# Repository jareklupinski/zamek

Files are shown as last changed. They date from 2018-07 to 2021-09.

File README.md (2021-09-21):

# Zamek
Your Digital Keychain.

I want to design the digital equivalent to the analog keychain. It keeps your passwords for you in an easy-to-use and portable, reliable design. It can be used completely standalone, but also with a Desktop App for easier data input.

Prototypes:

[Youtube Function Demo](https://www.youtube.com/watch?v=8wrW3907pkc)

Zamek Prototype 1

Zamek Prototype 2

Front View:
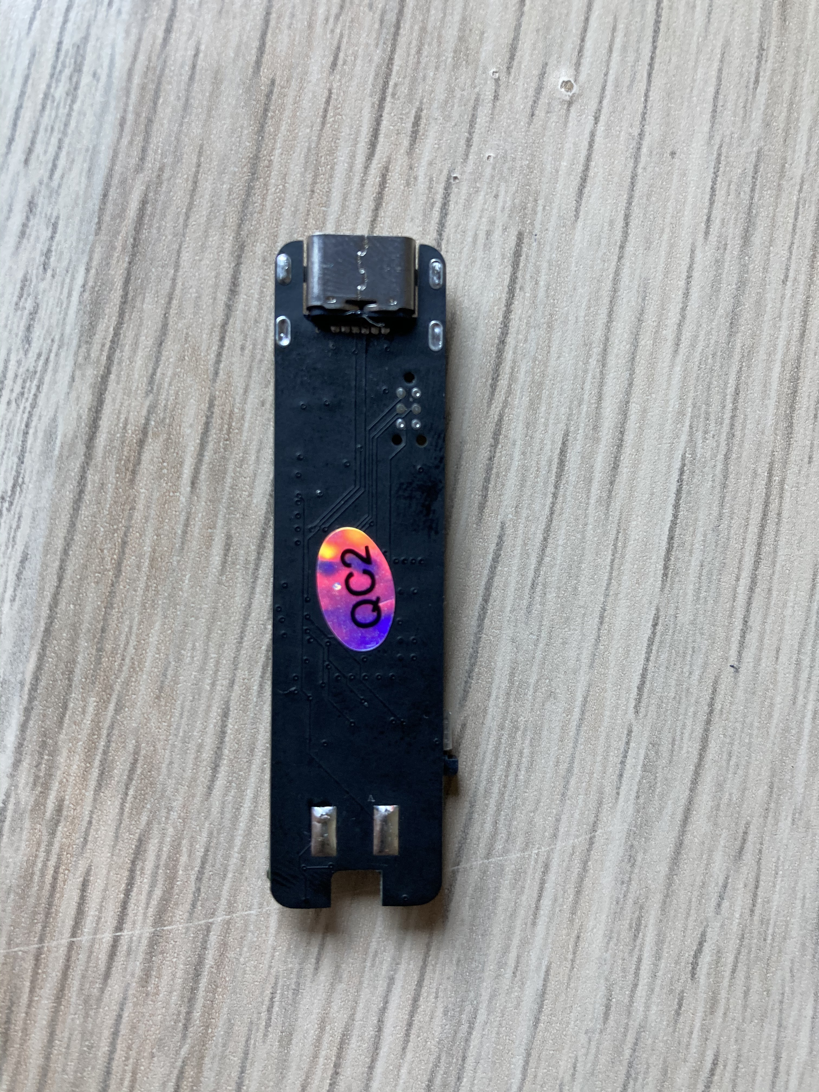
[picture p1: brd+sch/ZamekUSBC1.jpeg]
front-view


Back View:
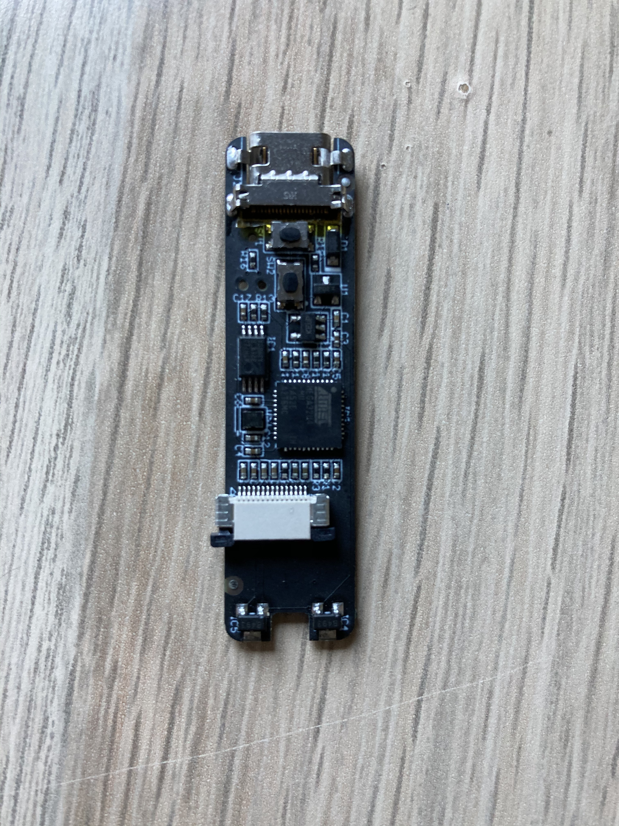
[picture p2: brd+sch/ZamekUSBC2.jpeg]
back-view


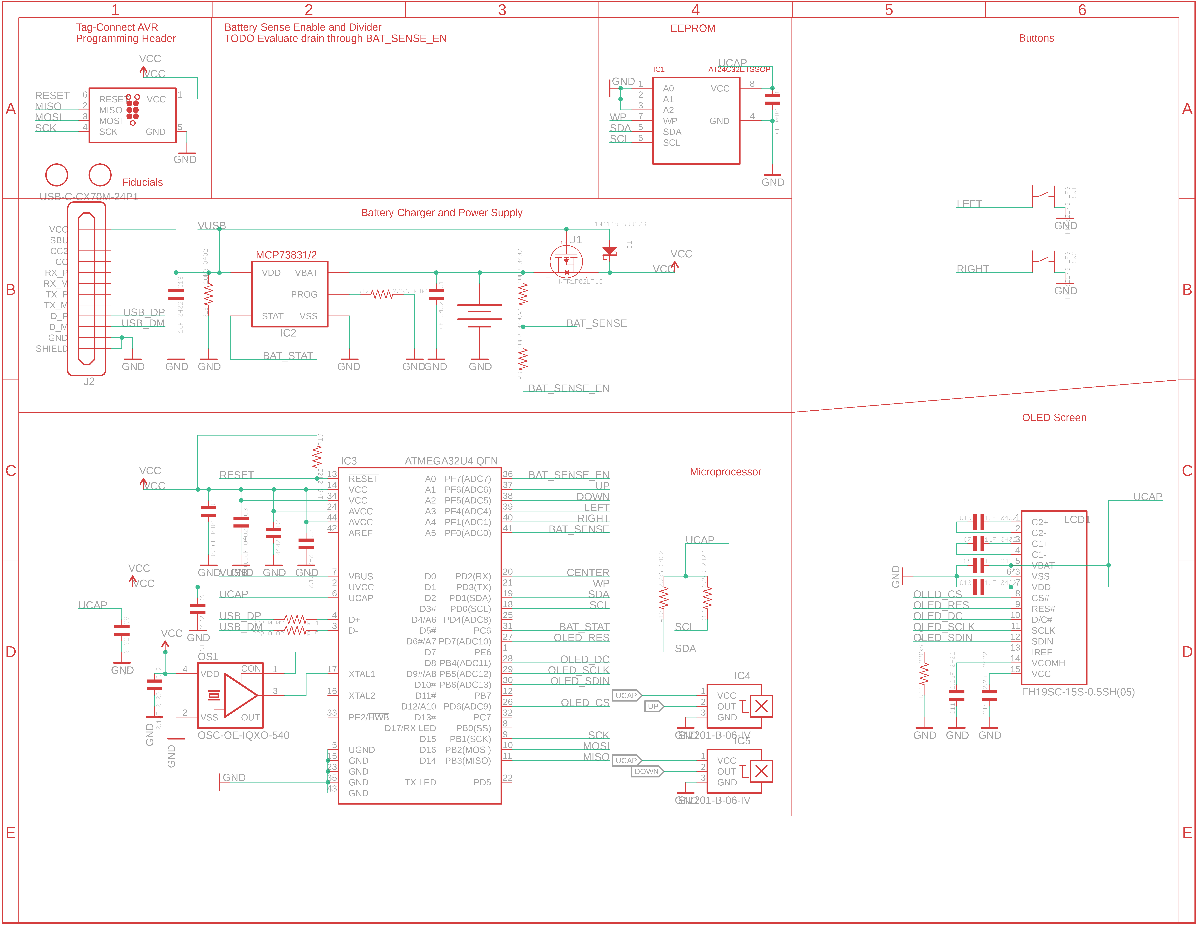
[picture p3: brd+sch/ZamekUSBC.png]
schematic


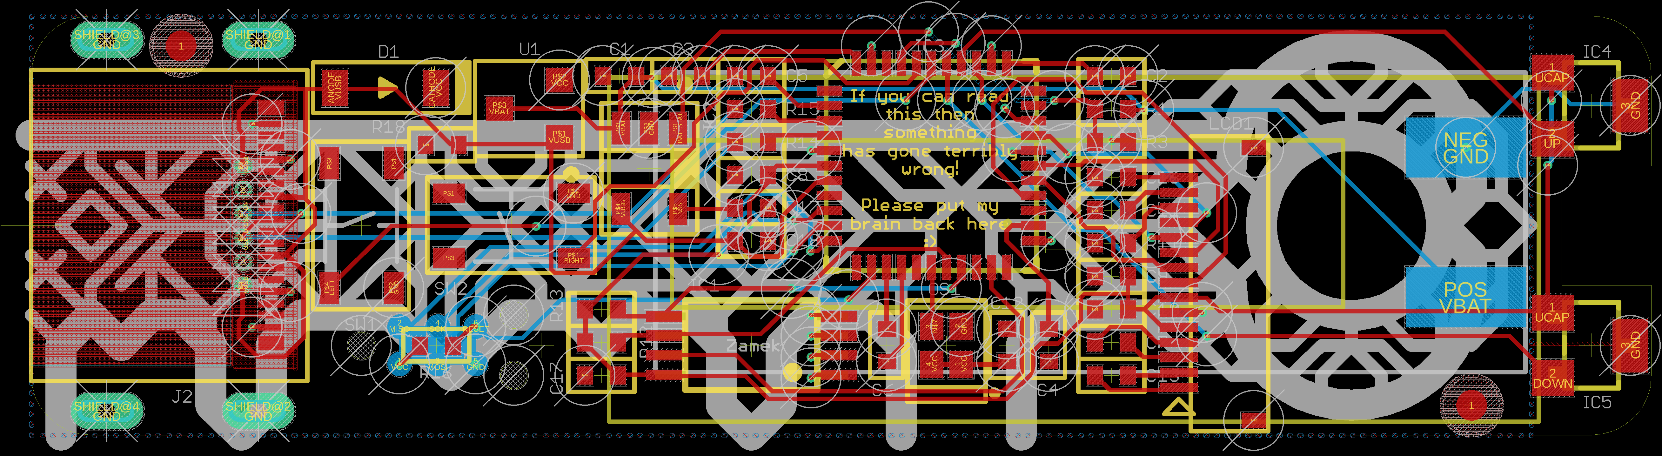
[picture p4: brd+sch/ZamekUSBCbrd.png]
board


This project is a Work-In-Progress; all contributions are welcome!

Project Layout:
* brd+sch contains hardware schematic
* desktop-app contains the desktop app
* zamek-src contains arduino source code

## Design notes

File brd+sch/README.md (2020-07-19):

Actual Schematic:
schematic

Component Layout:
board

Routed, produced, and smoke tested. Some validation with sensors to be done...

Front View:
front-view

Back View:
back-view

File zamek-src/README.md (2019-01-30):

# Arduino Sourcecode for the ATMega32U4

To compile this source code the AESLib is needed [AESLib](https://github.com/DavyLandman/AESLib). Just copy it in your Arduino lib folder.
Also configure Arduino to compile for "Leonardo Compatible" and hit compile. Some warnings are thrown, but the code should run. I've tested the build process on Arduino 1.6.7

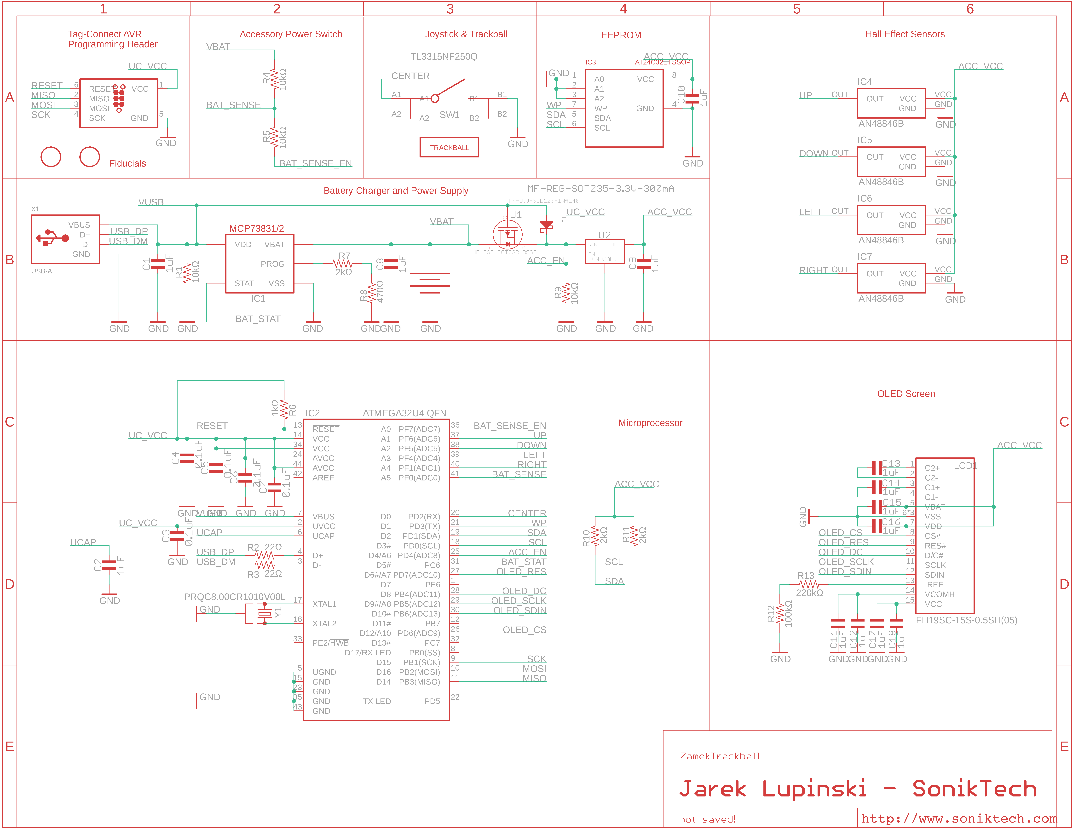
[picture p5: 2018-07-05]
brd+sch/zamek-schematic.png

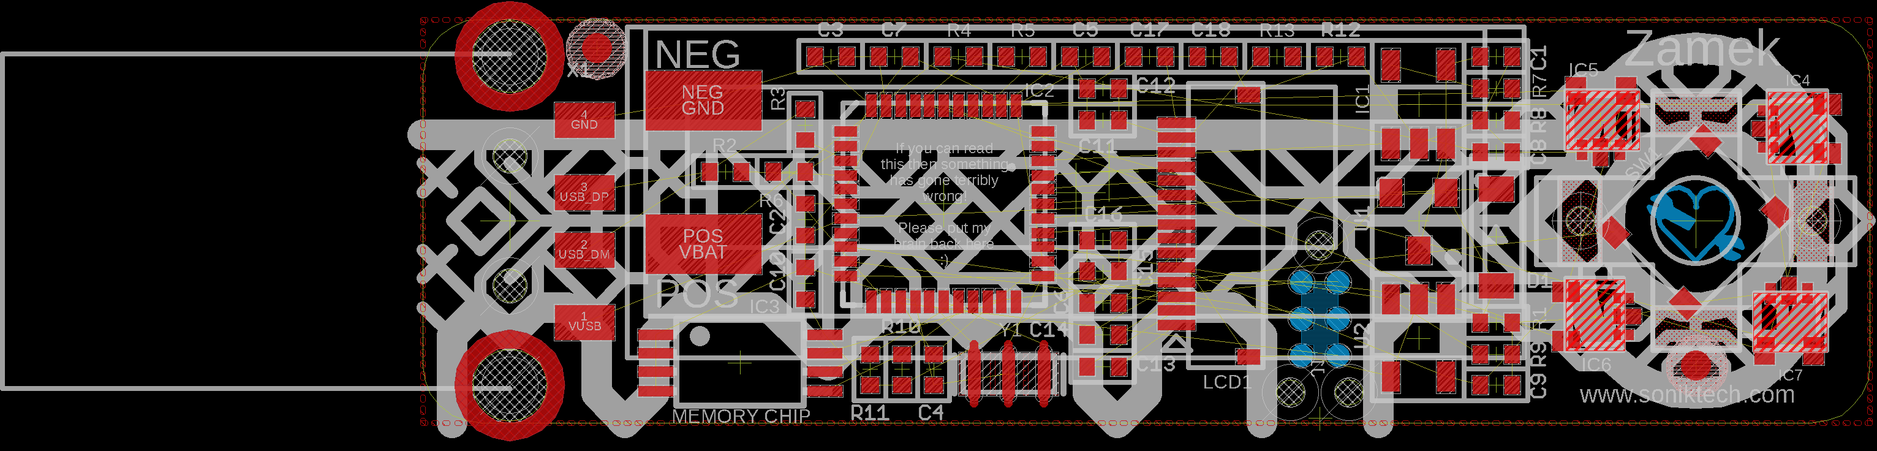
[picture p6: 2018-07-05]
brd+sch/zamek-board.png

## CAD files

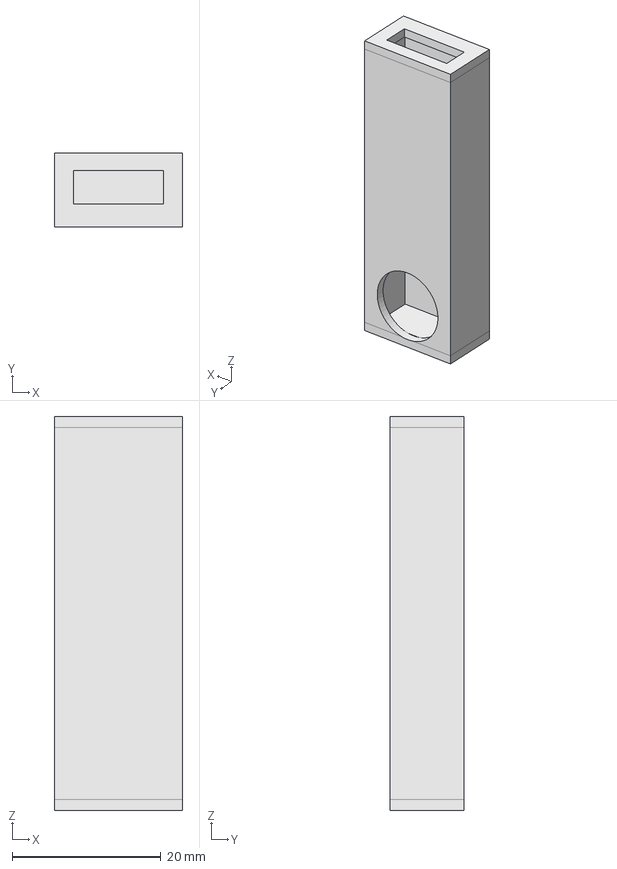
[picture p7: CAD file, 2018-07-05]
brd+sch/zamek.FCStd
17.2 x 10.0 x 53.0 mm

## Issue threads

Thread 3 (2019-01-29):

Serial Protocol undocumented and probably insecure?

vogt31337, 2019-01-29:
Hi,

just browsing through this repo and I like the project so far. But I don't find any docu on the serial protocol used: I just figured out sending a 'd' to the device, will dump the whole eeprom store.
I hope this is just for debugging, and Can be removed...

BR

jareklupinski, 2019-01-30:
Hi vogt, the intention for this is to allow a PC app attached to the Zamek's Serial Port to download the encrypted payload from the device for ease-of-use tasks like credential entry and backups. As only the encrypted blob can be downloaded, the PC still needs whichever key you put into the device to decrypt the contents. This will ( in the future ) be something the user has to toggle, something like a dialog will pop up on the device requesting the user to confirm their blob is about to be dumped before it actually connects and dumps.

-d for dump :)

Closed 2019-01-30.

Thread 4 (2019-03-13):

Security: weak key material used for encrypting passwords

rosly, 2019-03-13:
Hi,

Just by quick search I found this in zamekSecurity.unlock():
23: key[ i ] = pinArray[ i ];
28:   aes128_cbc_enc( key, iv, data, 48 )

Means that all the key entropy came from PIN, which can be from 1 to 16 ASCII digits.
Combining that with user tendency to use short PINs this solution is far from secure.
Obviously, for 4 digit PIN we have 9999 key space.
On my PC CPU only I would be able to crack data secured by this method up to 13 digits PIN just in one day.

Probably most of the people will use PINs far shorter than 13 digits.
That's just if we considering entropy. The key should never be pure ASCII string.
You need to use proper encryption scheme.

jareklupinski, 2019-03-13:
Hi! Thanks for opening this issue; security is one of the aspects of this project I wanted to compartmentalize to easily get and implement feedback.

My intentions for this device is to allow the user to choose their own security level. For example, I choose a 4-digit PIN for my Zamek because I am sure that I would be able to change all of my passwords in less than a day if I lose my device ( using a backup I keep at home ). Other people may choose longer passwords to get extra time.

The balance between convenience and security is tough and I want to leave this issue open for discussion :)

One idea I had was to initialize the password store with a completely random 16-digit number and allow the user to edit certain digits, e.g. your randomly generated seed is 123456789abcdef, and your PIN is 4031, then the seed would be 403156789abcdef. Storing these last few digits somewhere other than a secure store is a weakness, but it needs to be nonvolatile... I assume if someone has hardware access then they can dump your payload and anything else on the device at will, so at most this should give you some extra time to change your passwords if your device gets stolen.... This probably needs input from a security expert.

ventaquil, 2019-03-13:
In my opinion you should use [key derivation function](https://en.wikipedia.org/wiki/Key_derivation_function). This crypto scheme turns input into fixed-size key (for your usage it turns PIN into 128 bits length AES key).

You can use AES-KDF scheme (which is used by KeePass) or [PBKDF2](https://en.wikipedia.org/wiki/PBKDF2) (it is more flexible solution because you can choose pseudorandom function which determines security).

An additional advantage of using KDF is that this solution can stronger resist against offline attacks. You can check it on your own - just create KeePass database and in database's settings set _"1 second delay"_ to calculate how many iterations of KDF should be set to have 1 second computation of one password on your machine.

rosly, 2019-03-13:
Hi,

I know this is a long post but all this explanation is probably needed to clarify some misunderstandings.

Key entropy depends only on how random your key material is.
It didn't mater if you use 16 digits but edit only some of them as the entropy of this solution is exactly the same as if you enter only those random digits. You probably were thinking about hash salt, which is in fact one of the ways to harden the security but in vector of rainbow tables attack. Anyway to use this you need to use hashes for key material which was one elements of "proper encryption scheme".

But lets first clarify why your current PIN need to be long. The entropy of single ASCII digit is log2(10) = 3.322 bits (yes might seems odd that there are fraction of bits).
On the other hand the iCore5 makes 55 millions of AES128 blocks encryption per second.

It means that with 4 ASCII digit key material you have ~13bit entropy for the key, which is 2^14 - 1 = 16384 combinations that can be cracked with speed 55 millions tries per second in ~ 0.2ms
Which means if you lose your device you would need to have 0.2 millisecond reaction time :) (not to much)

Ok, that was a bit of nerd joke from my side ;)
So if we make our scenario more realistic. Lets assume that you will have reaction time of 6 hours (this includes time for spotting that you lost the device, like after returning home and time required to change all the passwords). If we also assume that the attacker would have 10 machines with 12 cores (which is not big number as you can buy 6h of computing time for such cluster under 10$ and as you already noted in your code you only need to decrypt first block of 16 bytes to reject garbage non ASCII output), that's 55M/s * 12 * 10 = 6.6 billions blocks per second. And that's not even close to what some guys have for serious cracking on GPU farms or zombie botnet.

So:
6.6*10^9 * 3600 * 6h = 1.4256*10^14 blocks decrypted during 6h window
log2(1.4256*10^14) = 47 bits entropy scanned during the 6h window
47/3.322 -> ~14 ASCII digit PIN
or 47/5.12 -> ~9 ASCII small letters and digits PIN

As you see those are rather long PINs. This might be problematic with current method of PIN input (or we should rather say password as those attacks are offline attack), as 14 digits is unpractical and 9 letter or digits might take a while to scroll through.

As the solution I propose:
- as I assume the power of HW device is that password is entered by different channel than PC (which can be intercepted) change the password input method for convenient way of providing long passwords (like touch screen)
- use hashing with salt and many rounds for key derivation method (like couple of thousands) to slow down the cracking process (ventaquil already proposed this while I was composing my reply ;))

jareklupinski, 2019-03-15:
Thank you for the detailed explanation @rosly, I have not been keeping up with how fast keys can be cracked on modern hardware, to me it makes sense to use both methods, and you are correct the current hardware limits the ease of inputting a long enough key.

I am thinking about a redesign of the way keys are generated and input by the user ( using hardware because I am more comfortable with hardware haha ) and need to do some more research on the easiest way for people to accurately replay a long enough key that will be useful to feed into @ventaquil's proposal :)

SatanRage, 2019-07-03:
what about a biometric fingerprint sensor, how hard can be to implement? i see that a lot of phone implement already that like Fingerprint-->hash from biometric data-->decrypt

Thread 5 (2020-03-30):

BOM and layout missing

Tobiassss, 2020-03-30:
Hi,

first: very nice project, thank you very much for all the effort you put into it!

I saw it and immediately want to build one by myself...
...BUT:
Why is there no complete BOM?
I mean you can takes some guesses and with some experience you'll find the parts. But especially for the Trackball, LiPo and OLED a little more information would be very convenient.

Why is the PCB not routed?
It seems that the Autorouter produces a functional design within a few seconds. But still, why not just share your proven design?

jareklupinski, 2020-05-05:
Unfortunately the proven design proved to be faulty :( the finished PCB needed three bodge wires to actually work, and I quickly began working on a completely different USB-C version to replace it.

I'm dragging my feet a bit with the firmware, but I'll post the USB-C board with the corrected traces soon :)

ryuk171, 2020-07-03:
i am new to all this it says nets missing , help!!

jareklupinski, 2020-07-19:
Hello! Thank you all for keeping on me about this :) I have uploaded the latest USBC variant that I am working on; unfortunately the older USB-A variant was impossible to produce cheaply while being waterproof.

The new version uses only two buttons and two hall effects sensors to read inputs from external rotary switches! https://github.com/jareklupinski/zamek/tree/master/brd%2Bsch

Working on the code now, PRs welcome and Stay tuned ;)

Closed 2020-07-19.

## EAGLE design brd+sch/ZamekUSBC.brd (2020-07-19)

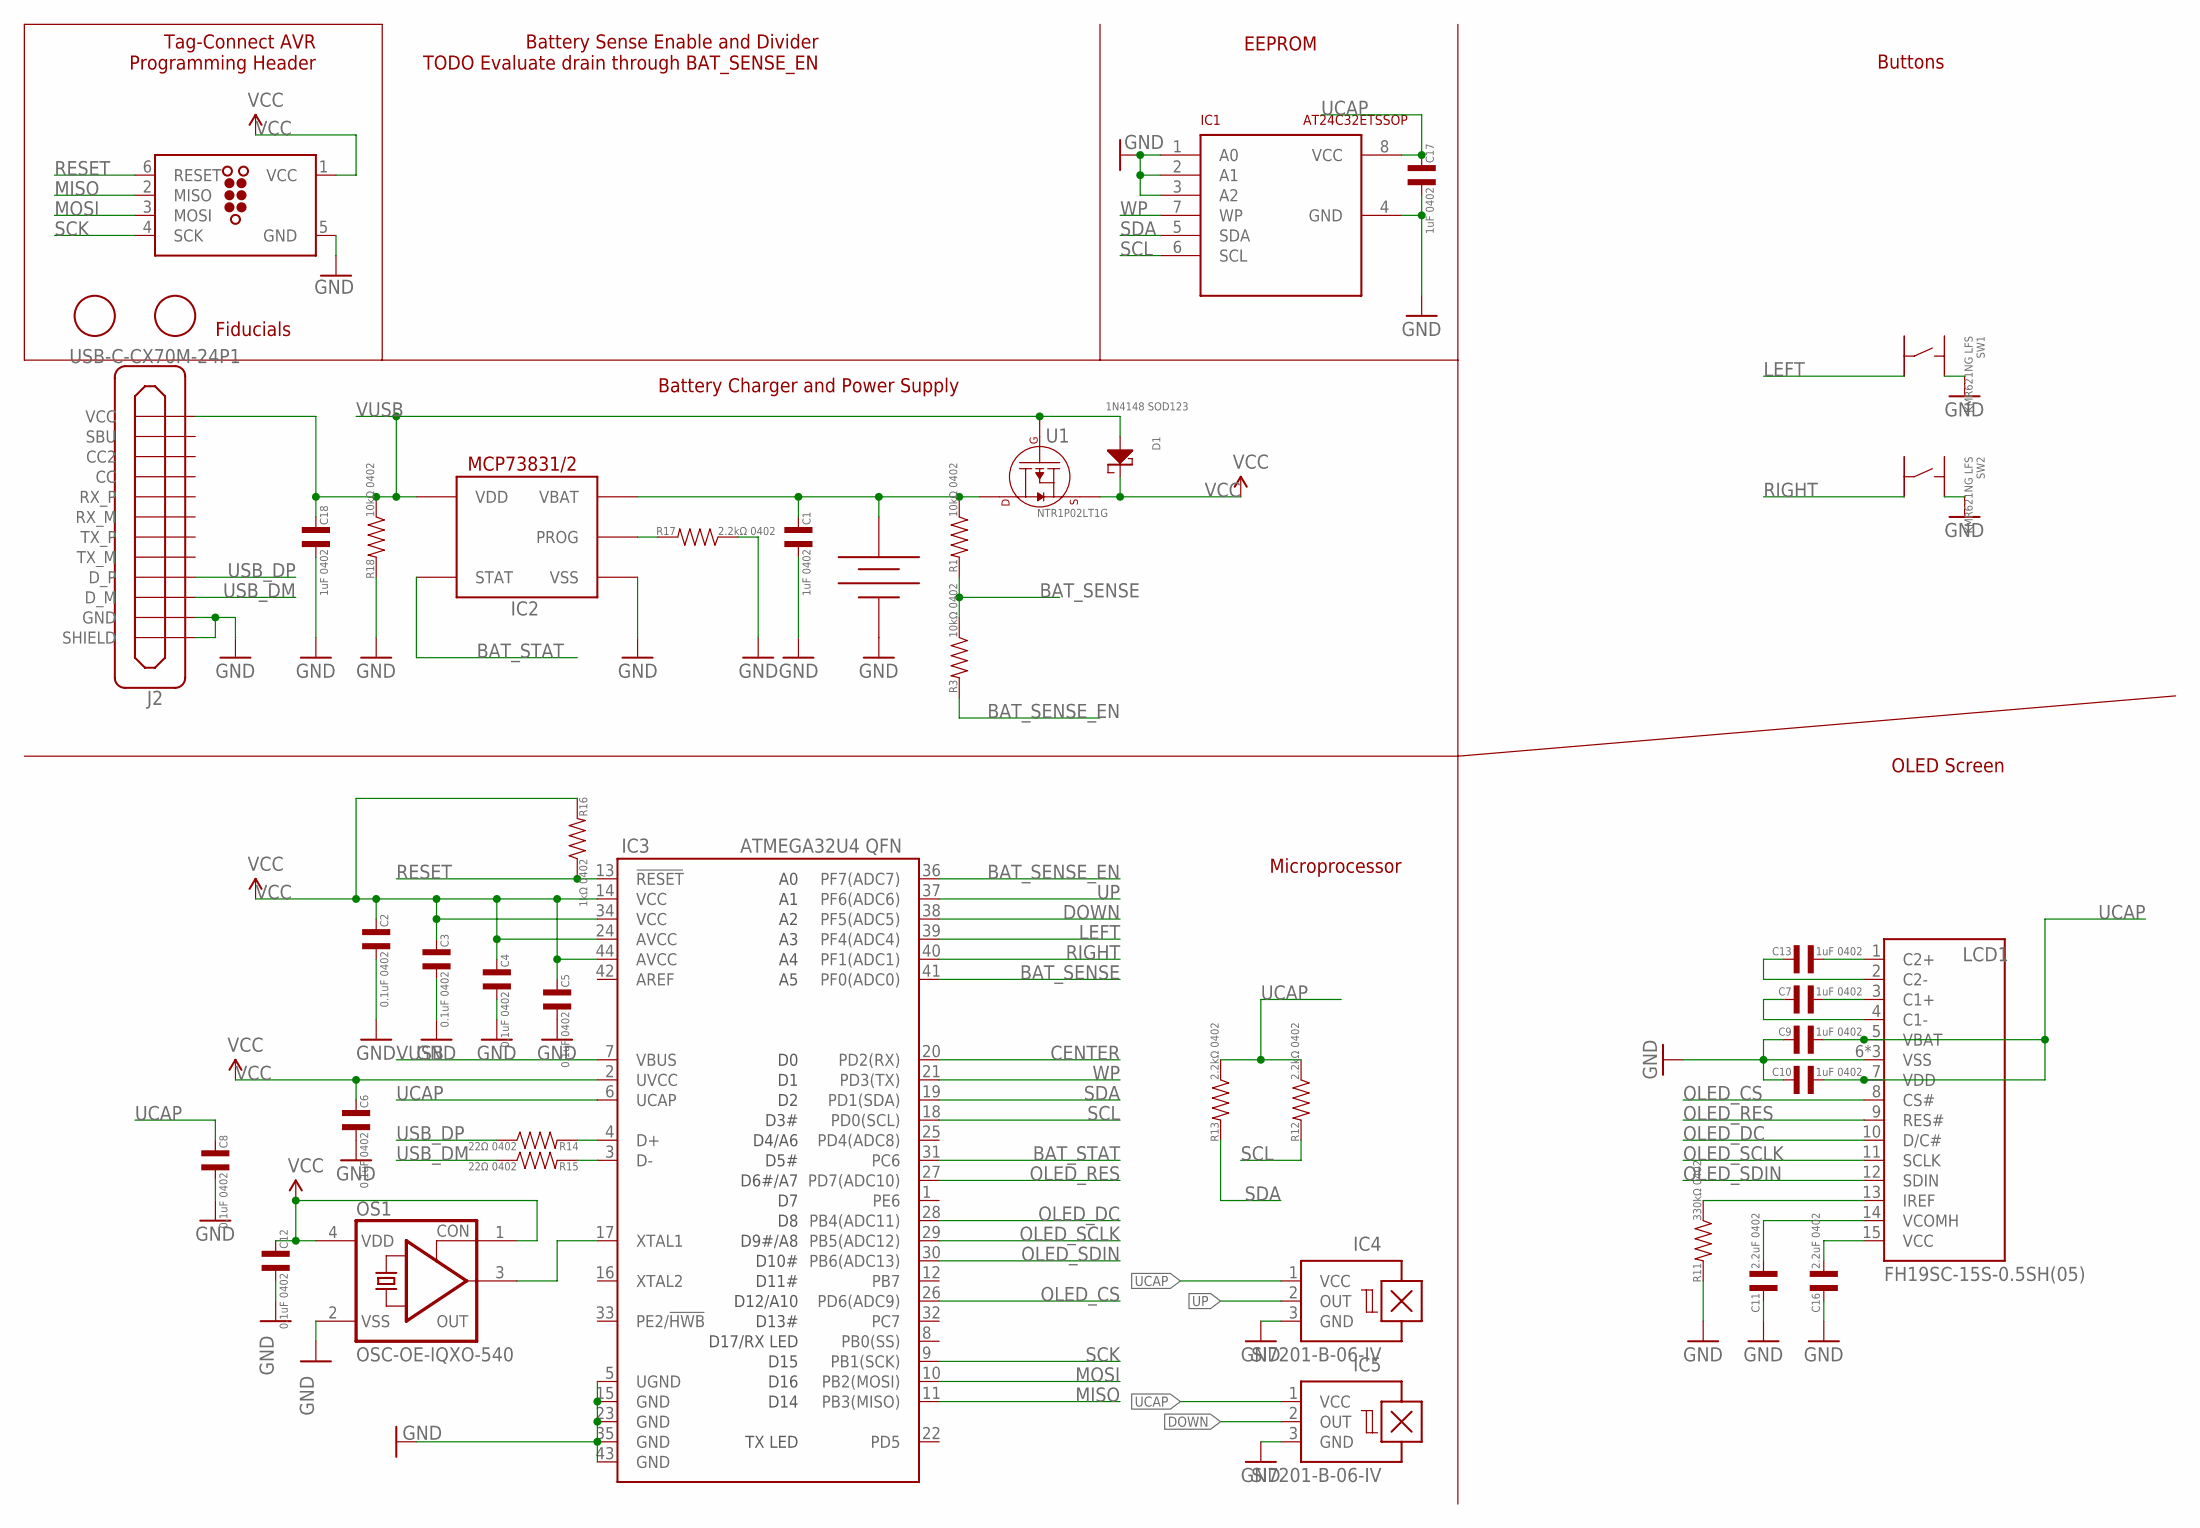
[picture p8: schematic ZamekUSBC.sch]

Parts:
BAT1: LIPO201030; 201030LIPO
C1, C7, C9, C10, C13, C17, C18: 1uF 0402; C0402
C2, C3, C4, C5, C6, C8, C12: 0.1uF 0402; C0402
C11, C16: 2.2uF 0402; C0402
D1: 1N4148 SOD123; SOD-123
IC1: AT24C32ETSSOP; TSSOP8-W
IC2: MCP73831; MFSOT23-5L
IC3: ATMEGA32U4 QFN; QFN-44-NOPAD
IC4, IC5: SI7201-B-06-IV; SOT23-W
J1: TC2030-MCP-NLFIX; TC2030-MCP-NL
J2: USB-C-CX70M-24P1; CX70M-24P1
LCD1: FH19SC-15S-0.5SH(05); ER-OLED0.91-3WWFH19C
OS1: OSC-OE-IQXO-540; 2.0X1.6-4-PAD
Q1, Q2: FIDUCIAL; FIDUCIAL_1MM
R1, R3, R18: 10kΩ 0402; R0402
R11: 330kΩ 0402; R0402
R12, R13, R17: 2.2kΩ 0402; R0402
R14, R15: 22Ω 0402; R0402
R16: 1kΩ 0402; R0402
SW1, SW2: KMR621NG LFS; TACT4.2MM
U1: NTR1P02LT1G; SOT-23-3

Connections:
BAT_SENSE: IC3.41 (PF0(ADC0)), R1.P$2, R3.P$1
BAT_SENSE_EN: IC3.36 (PF7(ADC7)), R3.P$2
BAT_STAT: IC2.P$1 (STAT), IC3.31 (PC6)
CENTER: IC3.20 (PD2(RX))
DOWN: IC3.38 (PF5(ADC5)), IC5.2 (OUT)
GND: BAT1.NEG, C1.P$1, C2.P$1, C3.P$1, C4.P$1, C5.P$1, C6.P$1, C8.P$1, C9.P$2, C10.P$2, C11.P$2, C12.P$1, C16.P$2, C17.P$1, C18.P$1, IC1.1 (A0), IC1.2 (A1), IC1.3 (A2), IC1.4 (GND), IC2.P$2 (VSS), IC3.5 (UGND), IC3.15 (GND), IC3.23 (GND), IC3.35 (GND), IC3.43 (GND), IC4.3 (GND), IC5.3 (GND), J1.5 (GND), J2.A1 (GND), J2.A12 (GND), J2.B1 (GND), J2.B12 (GND), J2.SHIELD@1 (SHIELD), J2.SHIELD@2 (SHIELD), J2.SHIELD@3 (SHIELD), J2.SHIELD@4 (SHIELD), LCD1.6 (VSS), LCD1.EP1 (VSS), LCD1.EP2 (VSS), OS1.2 (VSS), R11.P$2, R17.P$1, R18.P$2, SW1.P$2, SW2.P$2
LEFT: IC3.39 (PF4(ADC4)), SW1.P$4
MISO: IC3.11 (PB3(MISO)), J1.2 (MISO)
MOSI: IC3.10 (PB2(MOSI)), J1.3 (MOSI)
unnamed: C13.P$2, LCD1.2 (C2-)
unnamed: C7.P$1, LCD1.3 (C1+)
unnamed: C7.P$2, LCD1.4 (C1-)
unnamed: C13.P$1, LCD1.1 (C2+)
unnamed: IC2.P$5 (PROG), R17.P$2
unnamed: IC3.4 (D+), R14.P$2
unnamed: IC3.17 (XTAL1), OS1.3 (OUT)
unnamed: LCD1.13 (IREF), R11.P$1
unnamed: C11.P$1, LCD1.14 (VCOMH)
unnamed: IC3.3 (D-), R15.P$2
unnamed: C16.P$1, LCD1.15 (VCC)
OLED_CS: IC3.26 (PD6(ADC9)), LCD1.8 (CS#)
OLED_DC: IC3.28 (PB4(ADC11)), LCD1.10 (D/C#)
OLED_RES: IC3.27 (PD7(ADC10)), LCD1.9 (RES#)
OLED_SCLK: IC3.29 (PB5(ADC12)), LCD1.11 (SCLK)
OLED_SDIN: IC3.30 (PB6(ADC13)), LCD1.12 (SDIN)
RESET: IC3.13 (!RESET), J1.6 (RESET), R16.P$1
RIGHT: IC3.40 (PF1(ADC1)), SW2.P$4
SCK: IC3.9 (PB1(SCK)), J1.4 (SCK)
SCL: IC1.6 (SCL), IC3.18 (PD0(SCL)), R12.P$2
SDA: IC1.5 (SDA), IC3.19 (PD1(SDA)), R13.P$2
UCAP: C8.P$2, C9.P$1, C10.P$1, C17.P$2, IC1.8 (VCC), IC3.6 (UCAP), IC4.1 (VCC), IC5.1 (VCC), LCD1.5 (VBAT), LCD1.7 (VDD), R12.P$1, R13.P$1
UP: IC3.37 (PF6(ADC6)), IC4.2 (OUT)
USB_DM: J2.A7 (D_M), J2.B7 (D_M), R15.P$1
USB_DP: J2.A6 (D_P), J2.B6 (D_P), R14.P$1
VBAT: BAT1.POS, C1.P$2, IC2.P$3 (VBAT), R1.P$1, U1.P$3 (DRAIN)
VCC: C2.P$2, C3.P$2, C4.P$2, C5.P$2, C6.P$2, C12.P$2, D1.CATHODE, IC3.2 (UVCC), IC3.14 (VCC), IC3.24 (AVCC), IC3.34 (VCC), IC3.44 (AVCC), J1.1 (VCC), OS1.1 (CON), OS1.4 (VDD), R16.P$2, U1.P$2 (SOURCE)
VUSB: C18.P$2, D1.ANODE, IC2.P$4 (VDD), IC3.7 (VBUS), J2.A4 (VCC), J2.A9 (VCC), J2.B4 (VCC), J2.B9 (VCC), R18.P$1, U1.P$1 (GATE)
WP: IC1.7 (WP), IC3.21 (PD3(TX))

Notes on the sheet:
Tag-Connect AVR Programming Header
Battery Charger and Power Supply
Microprocessor
Battery Sense Enable and Divider TODO Evaluate drain through BAT_SENSE_EN
OLED Screen
Buttons
EEPROM
Fiducials

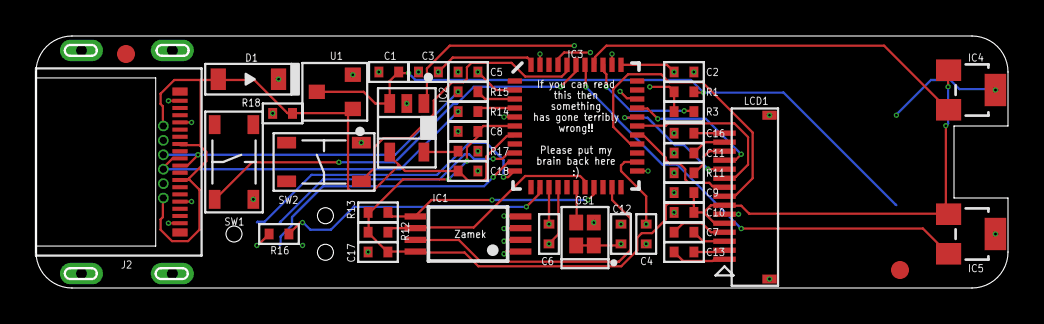
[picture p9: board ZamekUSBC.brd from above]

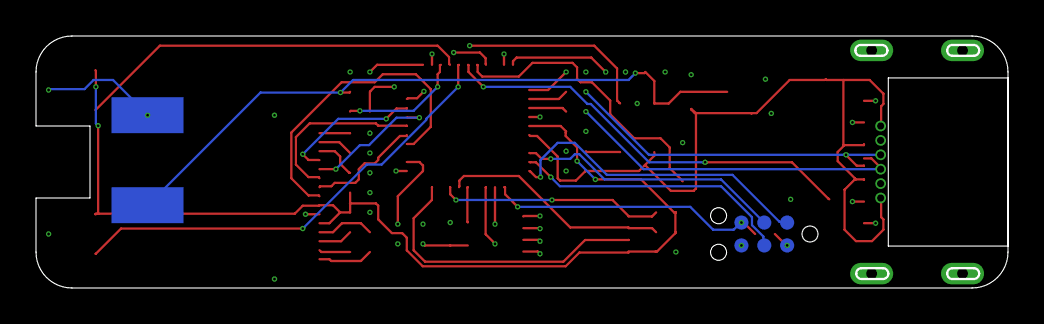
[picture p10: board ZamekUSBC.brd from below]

Board: 4 copper layers, 54.0 x 14.0 mm, 42 parts (2 on the bottom side), 37 nets.

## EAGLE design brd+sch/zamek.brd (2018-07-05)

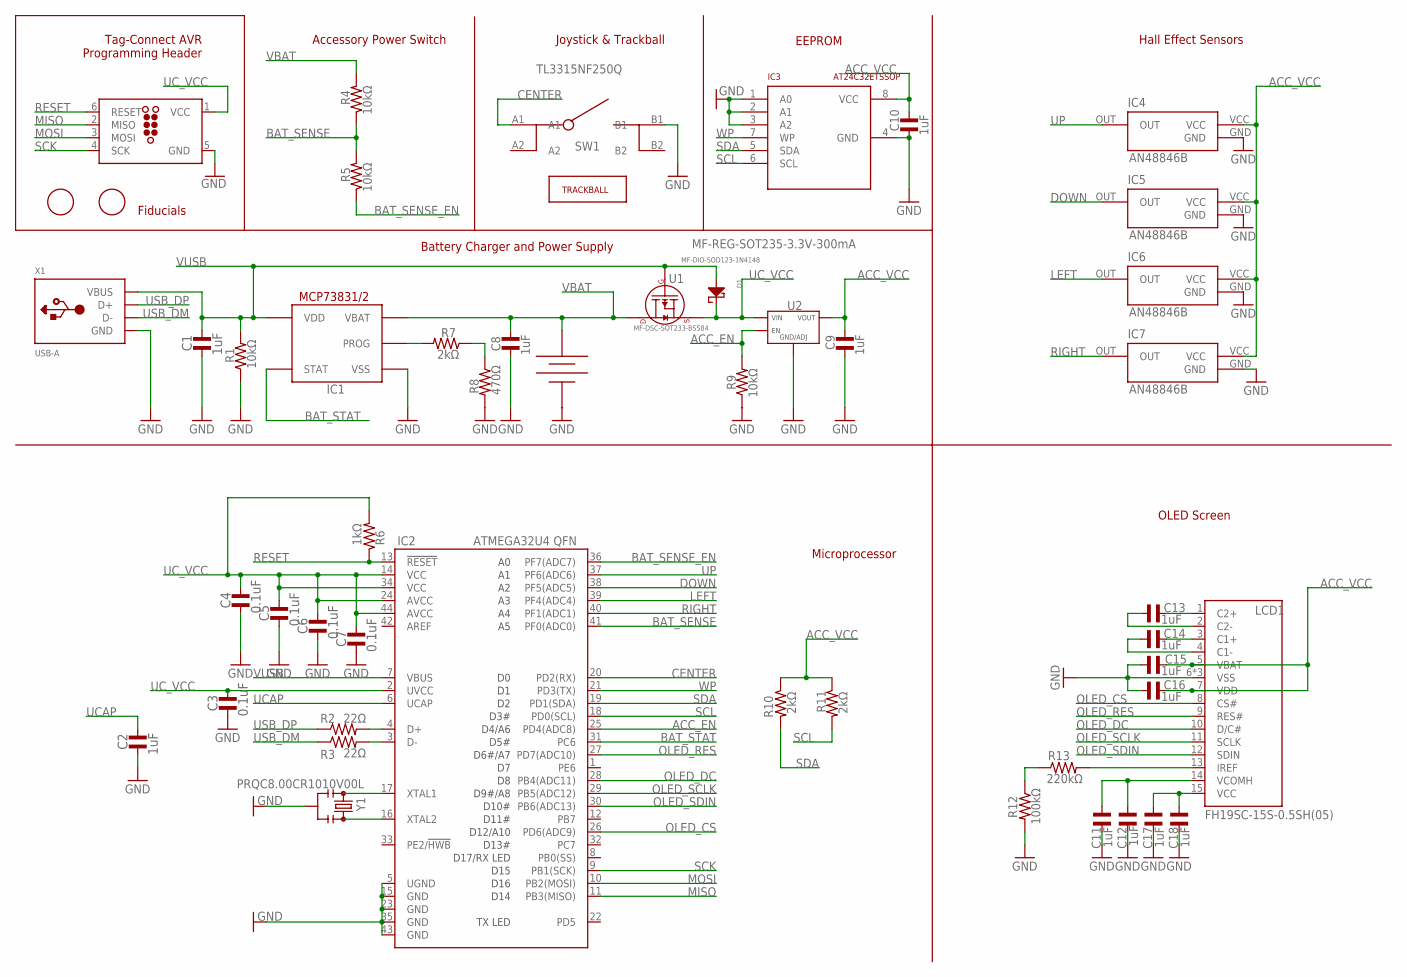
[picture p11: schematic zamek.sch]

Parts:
BAT1: LIPO201030; 201030LIPO
C1, C2, C8, C9, C10, C11, C12, C13, C14, C15, C16, C17, C18: 1uF; C0402
C3, C4, C5, C6, C7: 0.1uF; C0402
D1: MF-DIO-SOD123-1N4148; SOD-123
IC1: MCP73831; MFSOT23-5L
IC2: ATMEGA32U4 QFN; QFN-44-NOPAD
IC3: AT24C32ETSSOP; TSSOP8-W
IC4, IC5, IC6, IC7: AN48846B; HALLSENSOR
J1: TC2030-MCP-NLFIX; TC2030-MCP-NL
LCD1: FH19SC-15S-0.5SH(05); ER-OLED0.91-3WWFH19C
R1, R4, R5, R9: 10kΩ; R0402
R2, R3: 22Ω; R0402
R6: 1kΩ; R0402
R7, R10, R11: 2kΩ; R0402
R8: 470Ω; R0402
R12: 100kΩ; R0402
R13: 220kΩ; R0402
SW1: TL3315NF250Q; TRACKBALLBUTTON
SW2: TRACKBALLMECH; TRACKBALL
U1: MF-DSC-SOT233-BSS84; SOT-23-3
U2: MF-REG-SOT235-3.3V-300mA; SOT-23-5
U$1, U$2: FIDUCIAL; FIDUCIAL_1MM
X1: USB-A; MOLEX_480371000
Y1: PRQC8.00CR1010V00L; RESONATOR-SMD

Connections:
ACC_EN: IC2.25 (PD4(ADC8)), R9.P$2, U2.P$3 (EN)
ACC_VCC: C9.P$1, C10.P$1, C15.P$2, C16.P$1, IC3.8 (VCC), IC4.VCC, IC5.VCC, IC6.VCC, IC7.VCC, LCD1.5 (VBAT), LCD1.7 (VDD), R10.P$1, R11.P$1, U2.P$5 (VOUT)
BAT_SENSE: IC2.41 (PF0(ADC0)), R4.P$1, R5.P$2
BAT_SENSE_EN: IC2.36 (PF7(ADC7)), R5.P$1
BAT_STAT: IC1.P$1 (STAT), IC2.31 (PC6)
CENTER: IC2.20 (PD2(RX)), SW1.A1
DOWN: IC2.38 (PF5(ADC5)), IC5.OUT
GND: BAT1.NEG, C1.P$2, C2.P$2, C3.P$2, C4.P$2, C5.P$2, C6.P$2, C7.P$2, C8.P$2, C9.P$2, C10.P$2, C11.P$2, C12.P$2, C15.P$1, C16.P$2, C17.P$2, C18.P$2, IC1.P$2 (VSS), IC2.5 (UGND), IC2.15 (GND), IC2.23 (GND), IC2.35 (GND), IC2.43 (GND), IC3.1 (A0), IC3.2 (A1), IC3.3 (A2), IC3.4 (GND), IC4.GND, IC5.GND, IC6.GND, IC7.GND, J1.5 (GND), LCD1.6 (VSS), LCD1.EP1 (VSS), LCD1.EP2 (VSS), R1.P$1, R8.P$2, R9.P$1, R12.P$2, SW1.B1, U2.P$2 (GND/ADJ), U2.P$4 (GND/ADJ), X1.4 (GND), Y1.2
LEFT: IC2.39 (PF4(ADC4)), IC6.OUT
MISO: IC2.11 (PB3(MISO)), J1.2 (MISO)
MOSI: IC2.10 (PB2(MOSI)), J1.3 (MOSI)
unnamed: C13.P$1, LCD1.2 (C2-)
unnamed: C14.P$2, LCD1.3 (C1+)
unnamed: C14.P$1, LCD1.4 (C1-)
unnamed: C13.P$2, LCD1.1 (C2+)
unnamed: IC1.P$5 (PROG), R7.P$2
unnamed: R12.P$1, R13.P$1
unnamed: IC2.16 (XTAL2), Y1.3
unnamed: LCD1.13 (IREF), R13.P$2
unnamed: C11.P$1, C12.P$1, LCD1.14 (VCOMH)
unnamed: IC2.4 (D+), R2.P$2
unnamed: IC2.3 (D-), R3.P$2
unnamed: IC2.17 (XTAL1), Y1.1
unnamed: R7.P$1, R8.P$1
unnamed: C17.P$1, C18.P$1, LCD1.15 (VCC)
OLED_CS: IC2.26 (PD6(ADC9)), LCD1.8 (CS#)
OLED_DC: IC2.28 (PB4(ADC11)), LCD1.10 (D/C#)
OLED_RES: IC2.27 (PD7(ADC10)), LCD1.9 (RES#)
OLED_SCLK: IC2.29 (PB5(ADC12)), LCD1.11 (SCLK)
OLED_SDIN: IC2.30 (PB6(ADC13)), LCD1.12 (SDIN)
RESET: IC2.13 (!RESET), J1.6 (RESET), R6.P$1
RIGHT: IC2.40 (PF1(ADC1)), IC7.OUT
SCK: IC2.9 (PB1(SCK)), J1.4 (SCK)
SCL: IC2.18 (PD0(SCL)), IC3.6 (SCL), R11.P$2
SDA: IC2.19 (PD1(SDA)), IC3.5 (SDA), R10.P$2
UCAP: C2.P$1, IC2.6 (UCAP)
UC_VCC: C3.P$1, C4.P$1, C5.P$1, C6.P$1, C7.P$1, D1.CATHODE, IC2.2 (UVCC), IC2.14 (VCC), IC2.24 (AVCC), IC2.34 (VCC), IC2.44 (AVCC), J1.1 (VCC), R6.P$2, U1.P$2 (SOURCE), U2.P$1 (VIN)
UP: IC2.37 (PF6(ADC6)), IC4.OUT
USB_DM: R3.P$1, X1.2 (D-)
USB_DP: R2.P$1, X1.3 (D+)
VBAT: BAT1.POS, C8.P$1, IC1.P$3 (VBAT), R4.P$2, U1.P$3 (DRAIN)
VUSB: C1.P$1, D1.ANODE, IC1.P$4 (VDD), IC2.7 (VBUS), R1.P$2, U1.P$1 (GATE), X1.1 (VBUS)
WP: IC2.21 (PD3(TX)), IC3.7 (WP)

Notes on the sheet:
Tag-Connect AVR Programming Header
Battery Charger and Power Supply
Microprocessor
Joystick & Trackball
Accessory Power Switch
OLED Screen
Hall Effect Sensors
EEPROM
Fiducials

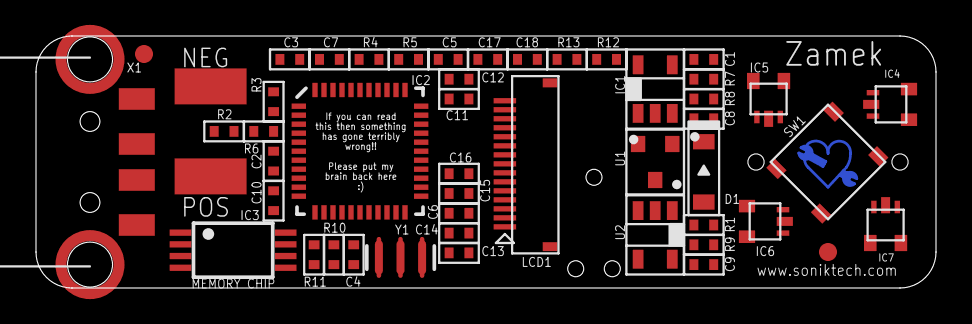
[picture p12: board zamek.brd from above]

Board: 4 copper layers, 50.0 x 14.0 mm, 50 parts (1 on the bottom side), 43 nets.

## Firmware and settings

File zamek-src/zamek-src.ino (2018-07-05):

#include "zamek-globals.h"                       //Include global header file

GLOBAL_VARIABLES                                //Declare list of global variables

//TODO List
// Set up WatchDog Timer ( dont forget to disable during sleep )
// Implement initialization feature which scrambles initial eeprom contents ( dont forget to add way to still dump contents in case of low-level corruption )
// Implement data integrity scanner ( use CRC32? )
// Re-enable sleep/lock on timeout
// Tighten up battery level thresholds
// ZamekDisplay class contains unused code

void setup() {
  Serial.begin( 9600 );                         //Initialize Serial Port
  analogReference( INTERNAL );                  //Measure ADC against internal reference
  pinMode( BUTTON_CENTER_PIN, INPUT_PULLUP );   //Set IO Pin Direction
  pinMode( BUTTON_LEFT_PIN,   INPUT_PULLUP );
  pinMode( BUTTON_RIGHT_PIN,  INPUT_PULLUP );
  pinMode( BUTTON_DOWN_PIN,   INPUT_PULLUP );
  pinMode( BUTTON_UP_PIN,     INPUT_PULLUP );
  pinMode( BAT_STAT_PIN,      INPUT_PULLUP );
  pinMode( BAT_SENSE_PIN,     INPUT );
  // pinMode( ACC_EN_PIN,        OUTPUT );
  pinMode( BAT_SENSE_EN_PIN,  OUTPUT );
  pinMode( EEPROM_WP_PIN,     OUTPUT );
  digitalWrite( BAT_SENSE_EN_PIN, HIGH );       //Set IO Pins to default states
  // digitalWrite( ACC_EN_PIN,       HIGH );
  zamekUtils.refreshBatteryLevel();             //Check battery level
  zamekDisplay.begin( SSD1306_SWITCHCAPVCC );   //Initialize OLED display
  zamekDisplay.display();
  while ( !digitalRead( BUTTON_CENTER_PIN ));   //Wait until center button is released
  Wire.begin();                                 //Initialize I2C
  //TODO evaluate ways of securely initializing the EEPROM
  //if ( EEPROM.read( 1023 ) != '*' ) initializeDevice();
  //TODO create an on-boot data integrity scanner
  EEPROM.update( 1023, 42 );
  attachInterrupt( 2, wakeInterrupt, FALLING ); //Set up center button to wake up from sleep
  programPosition = PIN_SCREEN;                 //Set program timeline to Pin Screen
  zamekDisplay.drawScreen();                    //Push data to screen and xhow it
}

void loop() {
  static unsigned long sleepTimer = 0;                        //Iniialize the timer used for going into timeout sleep mode
  while ( Serial.available() > 0 ) zamekUtils.handleSerial(); //Handle any Serial Communications
  if ( zamekIo.handleButtonChecker() ) {                      //Check the trackball and button for changes
    zamekUtils.refreshBatteryLevel();                         //Check battery status
    zamekDisplay.drawScreen();                                //Update Screen
    sleepTimer = millis();                                    //Reset timeout
  }
  //if (( sleepTimer + 60000 ) < millis() ) zamekSleep.start(); //No activity timeout
}

void wakeInterrupt() {}

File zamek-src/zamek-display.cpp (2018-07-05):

#include "zamek-display.h"

GLOBAL_VARIABLES

static uint8_t buffer[ 512 ] = { 0x00, 0x00, 0x00, 0x00, 0x00, 0x00, 0x00, 0x00, 0x00, 0x00, 0x00, 0x80, 0x40, 0x40, 0x20, 0x20, 0x20, 0x40, 0x40, 0x80, 0x80, 0x00, 0x80, 0x80, 0x40, 0x40, 0x20, 0x20, 0x20, 0x40, 0x40, 0x80, 0x80, 0xE0, 0xF0, 0x90, 0x80, 0xC0, 0x00, 0x00, 0x00, 0x00, 0x00, 0x00, 0xF0, 0x10, 0x10, 0xF0, 0x80, 0x80, 0xF0, 0x10, 0x10, 0xF0, 0x80, 0x80, 0xF0, 0x10, 0x10, 0xF0, 0x00, 0x00, 0x00, 0x00, 0x00, 0x00, 0x10, 0x10, 0x10, 0x10, 0x10, 0x10, 0x10, 0x10, 0x10, 0xF0, 0x00, 0x00, 0x00, 0x00, 0x00, 0x00, 0x00, 0x00, 0x00, 0x00, 0x00, 0x00, 0x00, 0x00, 0x00, 0x00, 0x00, 0x00, 0x00, 0x00, 0x00, 0x00, 0x00, 0x00, 0x00, 0x00, 0x00, 0x00, 0x00, 0x00, 0x00, 0x00, 0x00, 0x00, 0x00, 0x00, 0x00, 0x00, 0x00, 0xE0, 0x00, 0x00, 0x00, 0x00, 0x00, 0x00, 0x00, 0x00, 0x00, 0x00, 0x00, 0x00, 0x00, 0x00, 0x00, 0x00, 0x00, 0x00, 0x00, 0x00, 0x00, 0x3C, 0xC3, 0x00, 0x00, 0x00, 0x00, 0x00, 0x00, 0x00, 0x00, 0x00, 0x00, 0x01, 0x00, 0x00, 0x18, 0x38, 0x3C, 0x1C, 0x1E, 0x0E, 0x07, 0x07, 0xC3, 0x3F, 0x01, 0x01, 0x01, 0x00, 0x00, 0x00, 0x00, 0x00, 0x00, 0x00, 0xFF, 0x00, 0x00, 0x00, 0x00, 0x00, 0x30, 0xF8, 0xF8, 0x30, 0x00, 0x00, 0x00, 0x00, 0x00, 0xFF, 0x00, 0x00, 0x00, 0x00, 0x00, 0x00, 0x00, 0x00, 0x00, 0x00, 0x00, 0xC0, 0x30, 0x0C, 0x03, 0x00, 0x00, 0x00, 0x00, 0x00, 0x00, 0x80, 0x80, 0x40, 0x40, 0x40, 0x80, 0xC0, 0x00, 0x00, 0x00, 0xC0, 0x00, 0x80, 0x80, 0x00, 0x00, 0x00, 0x80, 0x80, 0x00, 0x00, 0x00, 0x00, 0x00, 0x00, 0x00, 0x80, 0x80, 0x80, 0x80, 0x00, 0x00, 0x00, 0x00, 0xFF, 0xC0, 0x20, 0x10, 0x08, 0x04, 0x00, 0x00, 0x00, 0x00, 0x00, 0x00, 0x00, 0x00, 0x00, 0x00, 0x00, 0x00, 0xC0, 0x60, 0x60, 0xE0, 0xF0, 0x70, 0x39, 0x3E, 0x1C, 0x18, 0x10, 0x20, 0x40, 0x80, 0x00, 0x00, 0x00, 0x00, 0x00, 0x80, 0x40, 0x20, 0x10, 0x08, 0x04, 0x02, 0x01, 0x00, 0x00, 0x00, 0x00, 0x00, 0x00, 0x00, 0x00, 0x00, 0x00, 0x00, 0x00, 0x7F, 0x80, 0x00, 0x00, 0x00, 0x10, 0x18, 0x1F, 0x1F, 0x18, 0x10, 0x00, 0x00, 0x00, 0x80, 0x7F, 0x00, 0x00, 0x00, 0x00, 0x00, 0x00, 0x00, 0xC0, 0x30, 0x0C, 0x03, 0x00, 0x00, 0x00, 0x00, 0x00, 0x00, 0x00, 0x00, 0xFE, 0x01, 0x00, 0x00, 0x00, 0x00, 0x00, 0x00, 0xFF, 0x00, 0x00, 0x00, 0xFF, 0x03, 0x00, 0x00, 0x03, 0xFC, 0x03, 0x00, 0x00, 0x03, 0xFC, 0x00, 0x00, 0x00, 0xFE, 0x11, 0x10, 0x10, 0x10, 0x10, 0x0F, 0x00, 0x00, 0x00, 0xFF, 0x00, 0x03, 0x0C, 0x30, 0xC0, 0x00, 0x00, 0x00, 0x00, 0x00, 0x00, 0x00, 0x00, 0x00, 0x00, 0x00, 0x00, 0x00, 0x00, 0x02, 0x03, 0x01, 0x00, 0x00, 0x00, 0x00, 0x00, 0x00, 0x00, 0x00, 0x00, 0x01, 0x02, 0x04, 0x02, 0x01, 0x00, 0x00, 0x00, 0x00, 0x00, 0x00, 0x00, 0x00, 0x00, 0x00, 0x00, 0x00, 0x00, 0x00, 0x00, 0x00, 0x00, 0x00, 0x00, 0x00, 0x00, 0x01, 0x02, 0x02, 0x04, 0x04, 0x04, 0x04, 0x04, 0x04, 0x04, 0x04, 0x02, 0x02, 0x01, 0x00, 0x00, 0x00, 0x00, 0x00, 0x00, 0x00, 0x07, 0x04, 0x04, 0x04, 0x04, 0x04, 0x04, 0x04, 0x04, 0x04, 0x00, 0x00, 0x00, 0x00, 0x03, 0x04, 0x04, 0x04, 0x04, 0x04, 0x02, 0x07, 0x00, 0x00, 0x00, 0x07, 0x00, 0x00, 0x00, 0x00, 0x07, 0x00, 0x00, 0x00, 0x00, 0x07, 0x00, 0x00, 0x00, 0x00, 0x03, 0x04, 0x04, 0x04, 0x04, 0x04, 0x00, 0x00, 0x00, 0x07, 0x00, 0x00, 0x00, 0x00, 0x00, 0x03, 0x04, 0x00, 0x00, 0x00, 0x00, 0x00 };

void ZamekDisplay::renderPinScreen() {          //put the PIN Screen in the buffer
  wipeScreen();
  setTextSize( 3 );
  for ( int i = 0; i < pinIndex; i++ ) {
    if ( 82 - ( 17 * i ) > -4 ) { //ugh
      setCursor( 82 - ( 17 * i ), 6 );
      print( pinArray[ pinIndex - ( i + 1 ) ] );
    }
  }
  drawBitmap( 104, 0, pinFrame, 24, 32, WHITE );
  setCursor( 109, 6 );
  setTextColor( BLACK, WHITE );
  print( numpadIndex );
}

void ZamekDisplay::renderMainScreen() {         //put the Main Screen in the buffer
  if ( programPosition == MAIN_INDEX ) {
    drawBitmap( 0, 0, arrows, 24, 8, WHITE );
    setTextColor( BLACK, WHITE );
  }
  else {
    drawBitmap( 0, 0, arrows, 24, 8, BLACK );
    setTextColor( WHITE );
  }
  setCursor( 6, 0 );
  print( siteIndex + 1 );
  setTextColor( WHITE );
  setCursor( 28, 0 );
  
    print( minLevel );
    write( '-' );
    print( batteryLevel );
    write( '-' );
    print( maxLevel );
  
  /*
    if ( USBSTA & ( 1 << VBUS )){
    setCursor( 32, 0 );
    setTextColor( WHITE );
    print( "Type" );
    }
  */
  drawBatteryIndicator();
  setCursor( 0, 8 );
  if ( programPosition == MAIN_SITE ) setTextColor( BLACK, WHITE );
  else setTextColor( WHITE );
  print("Site");
  setTextColor( WHITE );
  print(":");
  for ( int i = 0; i < 16; i++ ) print( currentSite[ i ] );
  setCursor( 0, 16 );
  if ( programPosition == MAIN_USER ) setTextColor( BLACK, WHITE );
  else setTextColor( WHITE );
  print("User");
  setTextColor( WHITE );
  print(":");
  for ( int i = 0; i < 16; i++ ) print( currentUser[ i ] );
  setCursor( 0, 24 );
  if ( programPosition == MAIN_PASS ) setTextColor( BLACK, WHITE );
  else setTextColor( WHITE );
  print("Pass");
  setTextColor( WHITE );
  print(":");
  for ( int i = 0; i < 16; i++ ) print( currentPass[ i ] );
}

void ZamekDisplay::renderEditScreen() {         //put the Edit Screen in the buffer
  switch ( typeIndex ) {
    case 0: print("Site:"); break;
    case 1: print("User:"); break;
    case 2: print("Pass:"); break;
  }
  for ( int i = 0; i < 16; i++ ) {
    if ( cursorIndex == i ) setTextColor( BLACK, WHITE );
    else setTextColor( WHITE );
    switch ( typeIndex ) {
      case 0: print( currentSite[ i ]); break;
      case 1: print( currentUser[ i ]); break;
      case 2: print( currentPass[ i ]); break;
    }
  }
  setTextColor( WHITE );
  print(" ");
  if ( programPosition == EDIT_LEFT_CURSOR ) setTextColor( BLACK, WHITE );
  else setTextColor( WHITE );
  print("<");
  if ( programPosition == EDIT_RIGHT_CURSOR ) setTextColor( BLACK, WHITE );
  else setTextColor( WHITE );
  print(">");
  setTextColor( WHITE );
  print(" ");
  print(" ");
  for ( int i = 0; i < 16; i++ ) {
    if (( programPosition == EDIT_KB1 ) && ( selectorIndex == i )) setTextColor( BLACK, WHITE );
    else setTextColor( WHITE );
    print( char( pgm_read_byte_near( keyboard1 + i + keyboardIndex )));
  }
  if ( programPosition == EDIT_RAND ) setTextColor( BLACK, WHITE );
  else setTextColor( WHITE );
  print("Rand");
  setTextColor( WHITE );
  print(" ");
  for ( int i = 0; i < 16; i++ ) {
    if (( programPosition == EDIT_KB2 ) && ( selectorIndex == i )) setTextColor( BLACK, WHITE );
    else setTextColor( WHITE );
    print( char( pgm_read_byte_near( keyboard2 + i + keyboardIndex )));
  }
  if ( programPosition == EDIT_BACK ) setTextColor( BLACK, WHITE );
  else setTextColor( WHITE );
  print("Save");
  setTextColor( WHITE );
  print(" ");
  for ( int i = 0; i < 16; i++ ) {
    if (( programPosition == EDIT_KB3 ) && ( selectorIndex == i )) setTextColor( BLACK, WHITE );
    else setTextColor( WHITE );
    print( char( pgm_read_byte_near( keyboard3 + i + keyboardIndex )));
  }
}
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

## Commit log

2018-07-05 design tested: working
    [zamek.FCStd, zamek.brd, zamek.sch]
2019-01-28 restructured the project, so that it will be easier for others to use.
    [zamek.FCStd, zamek.brd, zamek.sch]
2020-07-19 add usbc variant
    [ZamekUSBC.brd, ZamekUSBC.sch]

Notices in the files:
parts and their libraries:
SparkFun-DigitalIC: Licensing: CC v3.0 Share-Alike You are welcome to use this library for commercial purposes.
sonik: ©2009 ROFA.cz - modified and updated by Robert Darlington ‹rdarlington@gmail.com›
